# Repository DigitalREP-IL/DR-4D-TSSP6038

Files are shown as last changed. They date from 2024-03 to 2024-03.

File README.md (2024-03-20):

The DR-4 LRIR is a longer range reflective distance sensor showcasing the Vishay TSSP6038. The TSSP6038 includes a signal conditioning section to demodulate a 38kHz carrier for light source disturbance immunity (for example, changing sunlight or fluorescent illumination). An IR emitter and support circuitry complete this sensor evaluation solution. Two options are available for either a simple digital signal output (TSSP6038), or a variable pulsewidth "analog" output (TSSP6P38).

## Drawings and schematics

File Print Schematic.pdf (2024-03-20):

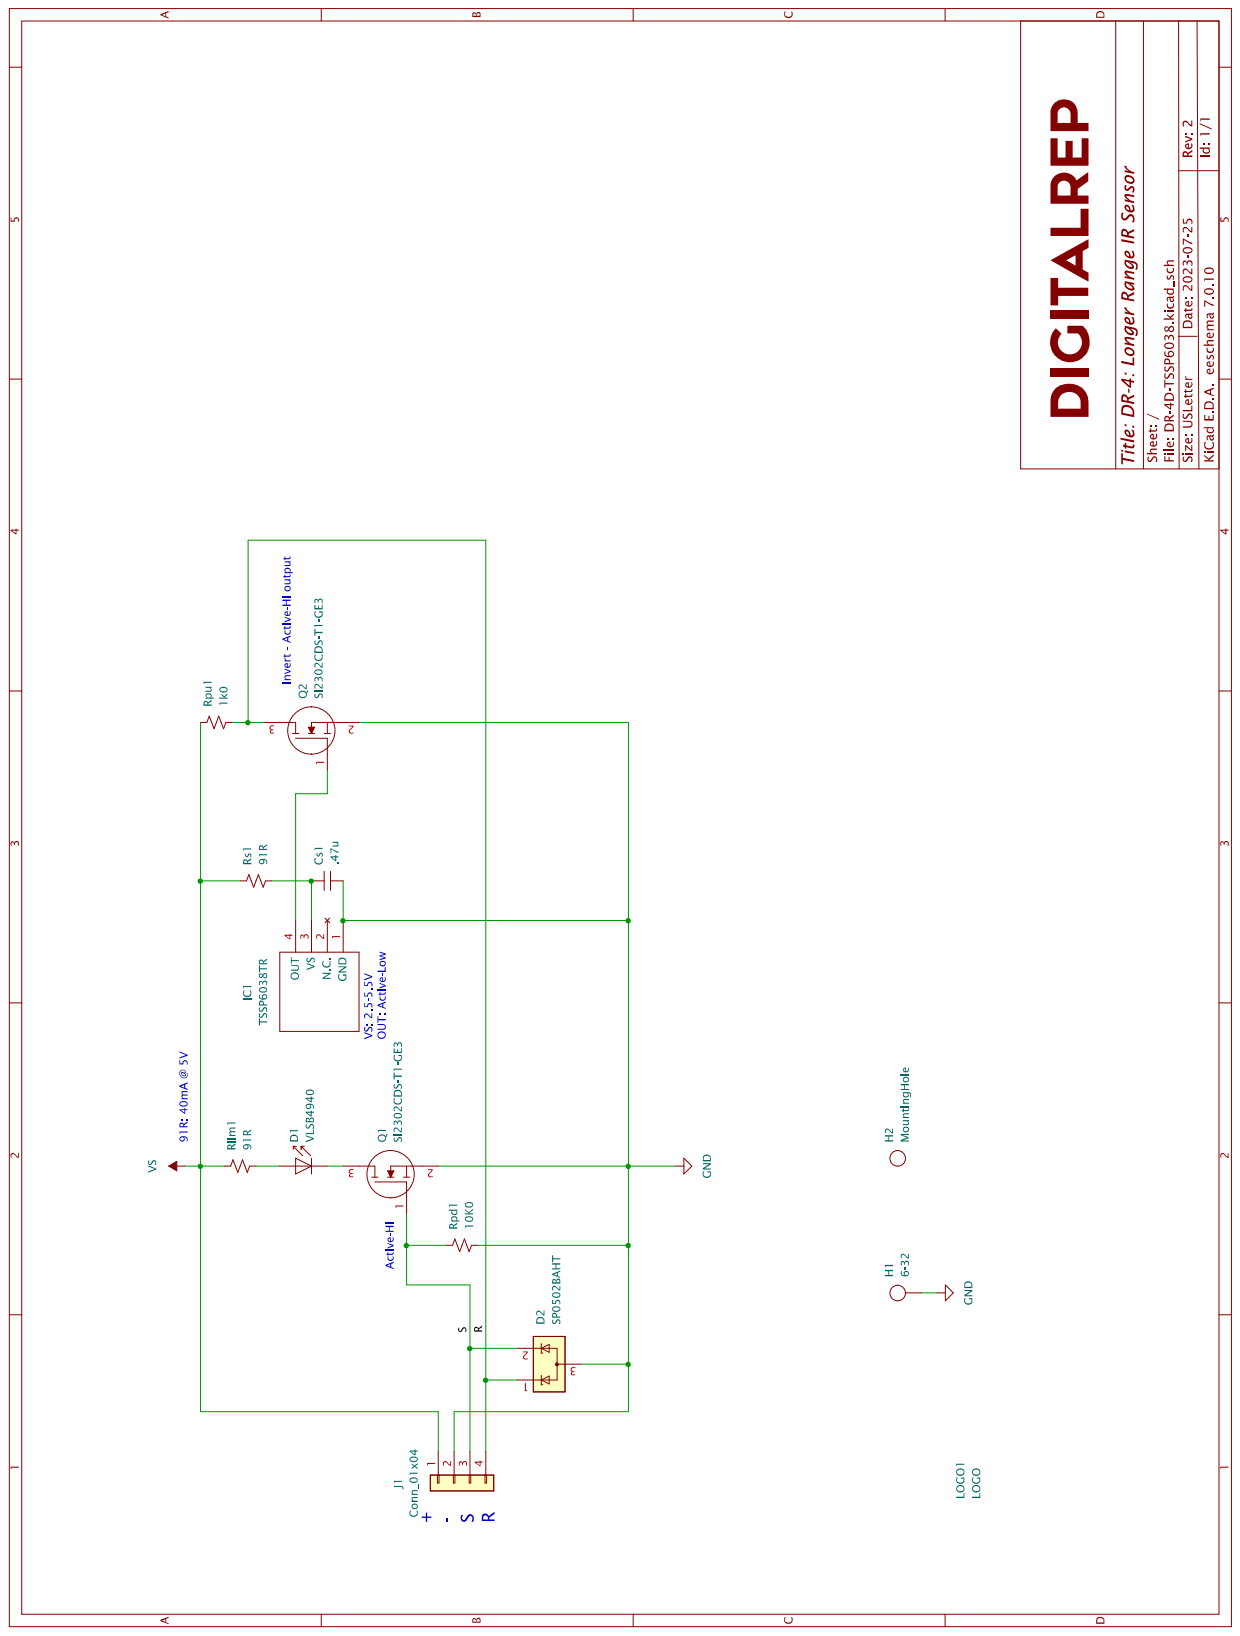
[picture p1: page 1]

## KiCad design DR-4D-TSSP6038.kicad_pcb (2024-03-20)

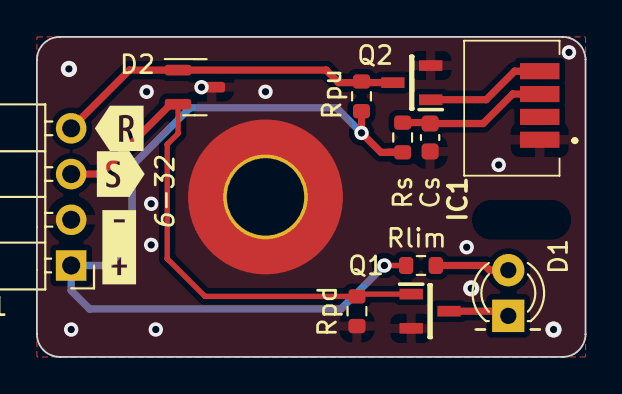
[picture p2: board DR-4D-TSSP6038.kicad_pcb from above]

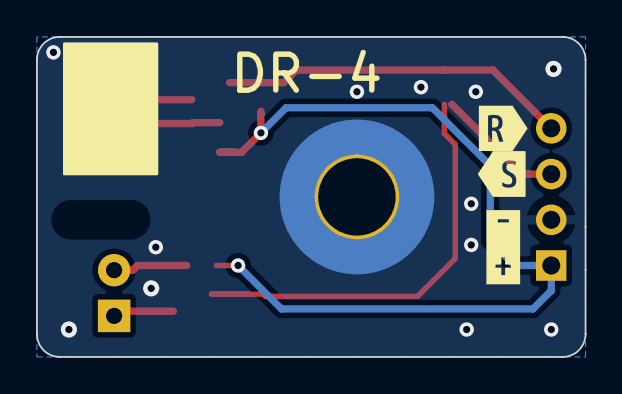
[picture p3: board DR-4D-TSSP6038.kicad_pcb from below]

Board: 2 copper layers, 30.5 x 17.8 mm, 20 parts (4 on the bottom side), 8 nets.

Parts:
Cs: .47u; C_0603_1608Metric
D1: VLSB4940; LED_D3.0mm_IRBlack
D2: SP0502BAHT; SOT-23
H1: 6-32; MountingHole_4.3mm_M4_Pad_TopBottom
H2: MountingHole; MountingHole_2.1mm
IC1: TSSP6038TR
J1: Conn_01x04; PinHeader_1x04_P2.54mm_Horizontal
LOGO1: LOGO; tinyrep
Q1: Si2302CDS-T1-GE3; SOT95P237X112-3N
Q2: SI2302CDS-T1-GE3; SOT95P237X112-3N
Rlim: 91R; R_0603_1608Metric
Rpd: 10K0; R_0603_1608Metric
Rpu: 1k0; R_0603_1608Metric
Rs: 91R; R_0603_1608Metric
kibuzzard-637672C4: G***; kibuzzard-637672C4
kibuzzard-6376729D: G***; kibuzzard-6376729D
kibuzzard-63767288: G***; kibuzzard-63767288
kibuzzard-63767574: G***; kibuzzard-63767574
kibuzzard-63767584: G***; kibuzzard-63767584
kibuzzard-63767593: G***; kibuzzard-63767593

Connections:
/R: D2.1 (K), J1.4, Q2.3, Rpu.2
/S: D2.2 (K), J1.3, Q1.1, Rpd.1
GND: Cs.2, D2.3 (A), H1.1, IC1.1 (GND), J1.2, Q1.2, Q2.2, Rpd.2
unnamed: D1.2 (A), Rlim.2
unnamed: D1.1 (K), Q1.3
unnamed: IC1.4 (OUT), Q2.1
unnamed: Cs.1, IC1.3 (VS), Rs.1
VS: J1.1, Rlim.1, Rpu.1, Rs.2

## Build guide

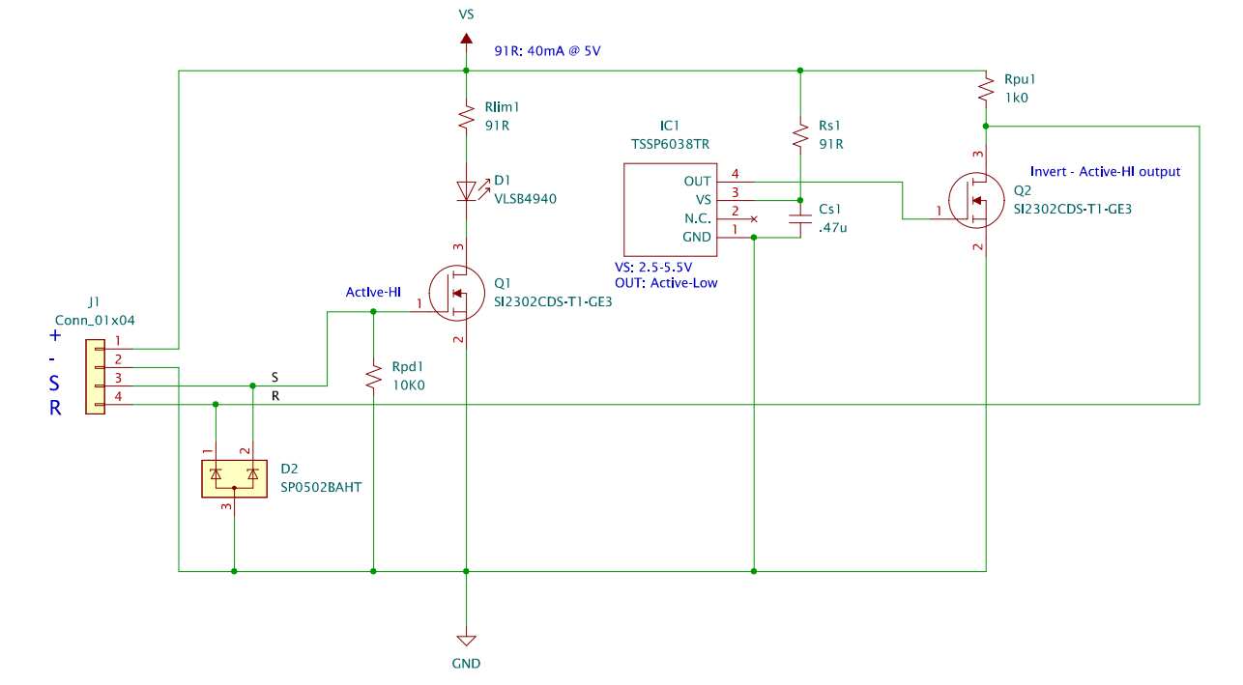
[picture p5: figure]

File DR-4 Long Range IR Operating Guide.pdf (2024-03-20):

# DR-4 Long Range IR Operating Guide

### DESIGN GOALS

The DR-4 LRIR is a longer range reflective distance sensor showcasing the Vishay TSSP6038. The TSSP6038 includes a signal conditioning section to demodulate a 38kHz carrier for light source disturbance immunity (for example, changing sunlight or fluorescent illumination). An IR emitter and support circuitry complete this sensor evaluation solution.

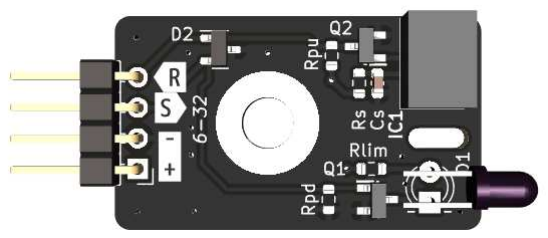
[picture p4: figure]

### DESIGN NOTES

Several features are included to make this sensor board a complete solution.

- Two Orderable Options:
- DR-4D-LRIR
- “digital” output from TSSP3068
- DR-4A-LRIR
- “analog” output from TSSP6P38
- ESD diodes on Send/Receive lines
- MOSFET buffers on input and output
- Send is Active-High
- Receive is Active-High
- Power supply filtering at IR Module for best performance
- 3dB cutoff ~37Hz
- VLSB4940 high performance IR Emitter
- 40mA at 5V supply
- Mounting holes and slots for IR blocking materials

### HOOKUP

As noted on the terminal markings, there are four connections:

+ | Supply | 3.3-5V
- | Ground | GND
S | Send | Modulated 38kHz input to sensor
R | Receive | Demodulated output from sensor
